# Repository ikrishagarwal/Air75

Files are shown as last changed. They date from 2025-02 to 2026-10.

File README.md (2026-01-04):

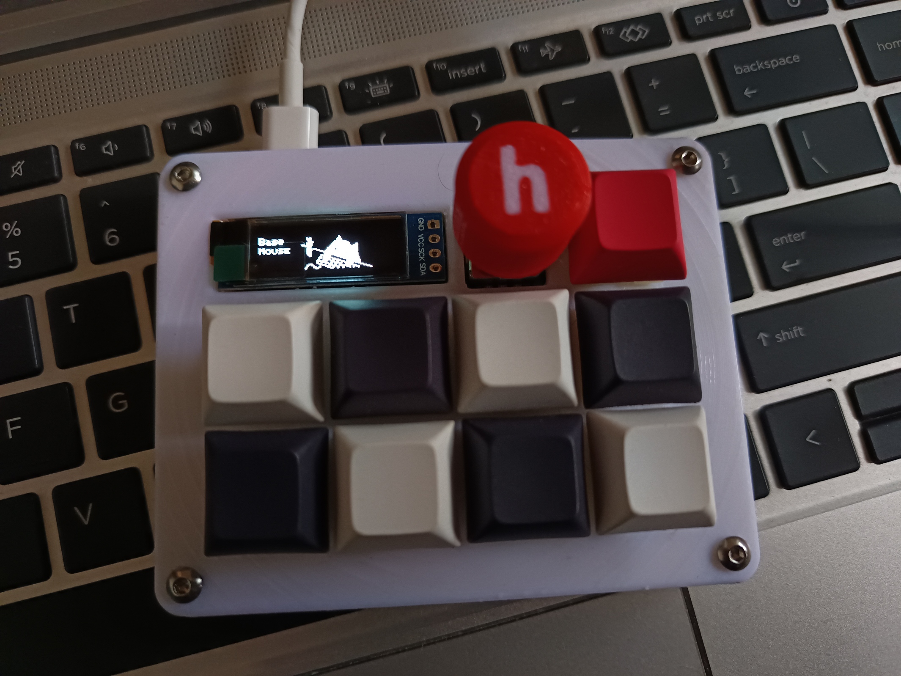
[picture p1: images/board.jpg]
air75


# Air 75

A Macro Pad with rotary encoders and OLED display.

## Specifications

### BOM

- 9x Cherry MX Switches
- 9x Blank DSA Keycaps (1x Red, 4x White, 4x Black)
- 1x Rotary Encoder
- 1x 128x32 OLED Display
- 10x 1N4148 Diodes
- 1x XIAO RP2040
- 4x M3x16 Bolt

# Features

- Rotary Encoder Support
- OLED Display Support
- VIA Support
- Based on QMK

### Other Resources

- [PCB](PCB)
- [Images](images)

| Schematic | PCB | Case |
| :---: | :---: | :---: |
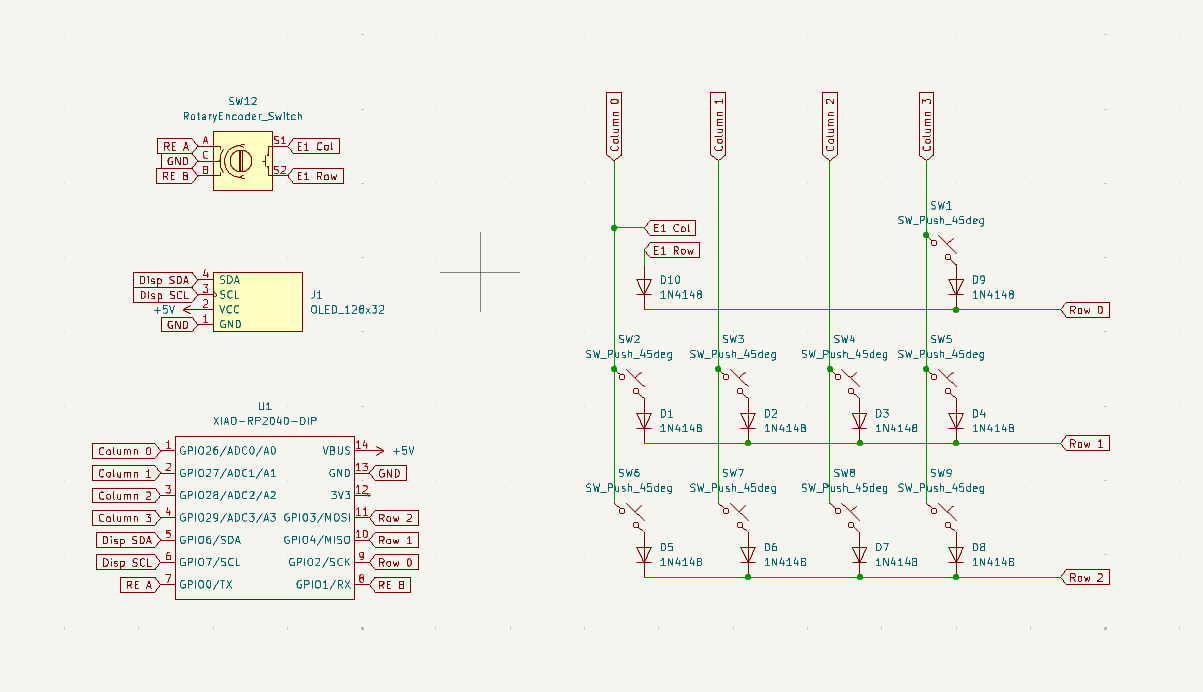
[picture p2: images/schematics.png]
schematic
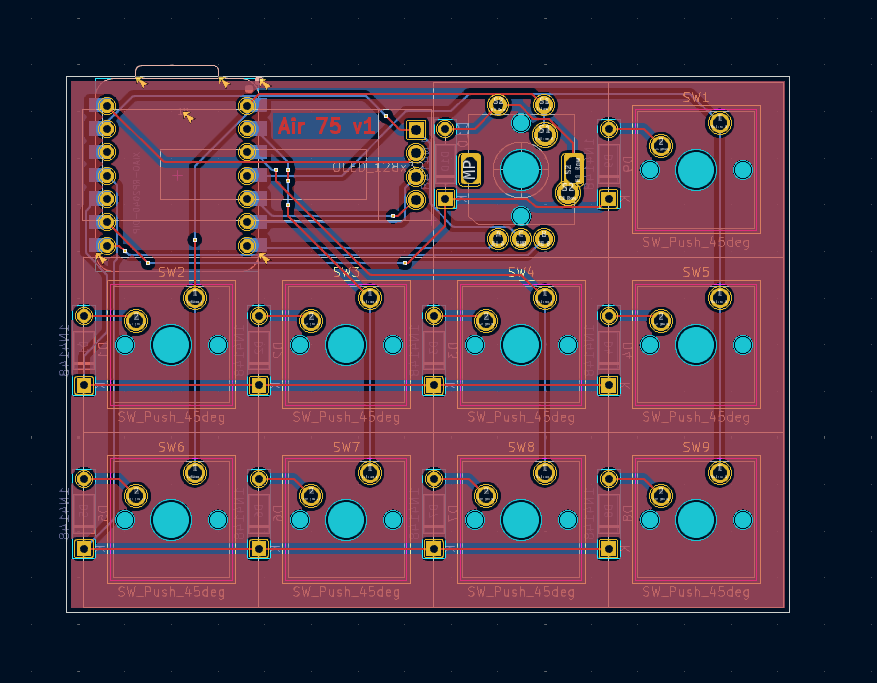
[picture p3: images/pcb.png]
pcb
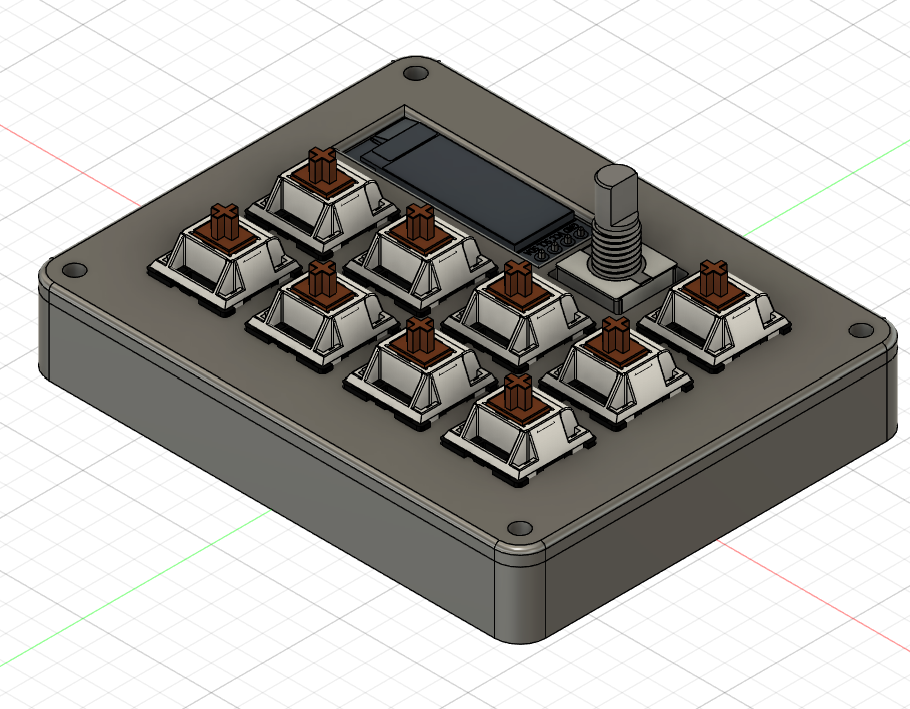
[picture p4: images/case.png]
case
|  |  |  |

## Author

- [Krish](https://github.com/ikrishagarwal)

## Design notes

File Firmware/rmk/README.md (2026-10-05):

# RMK 

RMK is a feature-rich and easy-to-use keyboard firmware.

## Air75 configuration

Edit `keyboard.toml` for the matrix pins and bootmagic key, encoder settings,
keymaps, Vim macro sequences, Vial/storage settings, and OLED hardware and redraw
intervals. RMK generates their setup; `src/main.rs` only invokes the keyboard macro.

The bongo-cat renderer and bitmap artwork remain in `src/bongocat_renderer.rs` and
`src/bongocat_frames.rs`. The build script derives OLED layer names and encoder
labels from the TOML's default keymap, so those labels need no separate Rust edits.
Labels describe the compiled defaults, not encoder mappings changed through Vial.

Use `clear_storage = false` to preserve saved Vial settings. Set it to `true`
only for an intentional reset, then restore `false` before normal use.

## Use the template

1. Install [probe-rs](https://github.com/probe-rs/probe-rs)

   ```shell
   # Linux/macOS
   curl --proto '=https' --tlsv1.2 -LsSf https://github.com/probe-rs/probe-rs/releases/latest/download/probe-rs-tools-installer.sh | sh

   # Windows
   irm https://github.com/probe-rs/probe-rs/releases/latest/download/probe-rs-tools-installer.ps1 | iex
   ```

2. Build the firmware

   ```shell
   cargo build --release
   ```

3. Flash using debug probe

   If you have a debug probe connected to your rp2040 board, flashing is quite simple: run the following command to automatically compile and flash RMK firmware to the board:

   ```shell
   cargo run --release
   ```

4. (Optional) Flash using USB

   If you don't have a debug probe, you can use `elf2uf2-rs` to flash your rp2040 firmware via USB. There are several additional steps you have to do:

   1. Install `elf2uf2-rs`: `cargo install elf2uf2-rs`
   2. Update `.cargo/config.toml`, use `elf2uf2` as the flashing tool
      ```diff
      - runner = "probe-rs run --chip RP2040"
      + runner = "elf2uf2-rs -d"
      ```
   3. Connect your rp2040 board holding the BOOTSEL key, ensure that rp's USB drive appears
   4. Flash
      ```shell
      cargo run --release
      ```
      Then, you will see logs like if everything goes right:
      ```shell
      Finished release [optimized + debuginfo] target(s) in 0.21s
      Running `elf2uf2-rs -d 'target\thumbv6m-none-eabi\release\rmk-rp2040'`
      Found pico uf2 disk G:\
      Transfering program to pico
      173.00 KB / 173.00 KB [=======================] 100.00 % 193.64 KB/s  
      ```

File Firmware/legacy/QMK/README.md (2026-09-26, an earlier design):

# Air75

air75

A Macro Pad designed for productivity and efficiency, featuring a rotary encoder and an OLED display for enhanced functionality.

- Keyboard Maintainer: [Krish](https://github.com/ikrishagarwal)
- Hardware Supported: _Seeed Xiao RP2040_

Make example for this keyboard (after setting up your build environment):

```
make air75:via
```

Flashing example for this keyboard:

```
make air75:via:flash
```

See the [build environment setup](https://docs.qmk.fm/#/getting_started_build_tools) and the [make instructions](https://docs.qmk.fm/#/getting_started_make_guide) for more information. Brand new to QMK? Start with our [Complete Newbs Guide](https://docs.qmk.fm/#/newbs).

## Bootloader

Enter the bootloader in 3 ways:

- **Bootmagic reset**: Hold down the Rotary Encoder and plug in the keyboard
- **Physical reset button**: Hold down the `boot` button on the Xiao and plug in the keyboard
- **Keycode in layout**: Press the key mapped to `QK_BOOT` if it is available

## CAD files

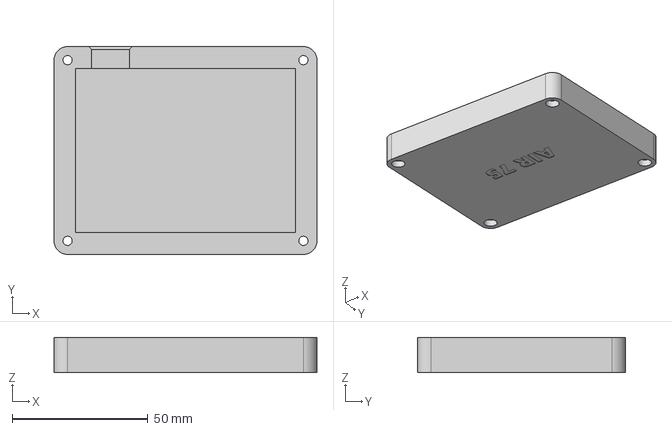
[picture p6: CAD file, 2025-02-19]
CAD/Bottom Case.step
96.7 x 76.5 x 13.0 mm

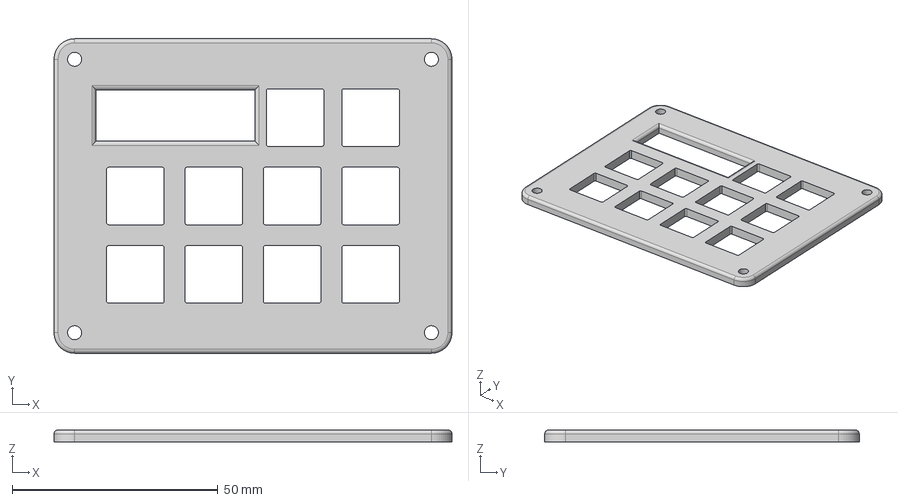
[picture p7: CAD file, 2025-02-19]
Production/Top Case.step
96.7 x 76.5 x 3.00 mm

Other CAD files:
CAD/Air75 v1.f3d

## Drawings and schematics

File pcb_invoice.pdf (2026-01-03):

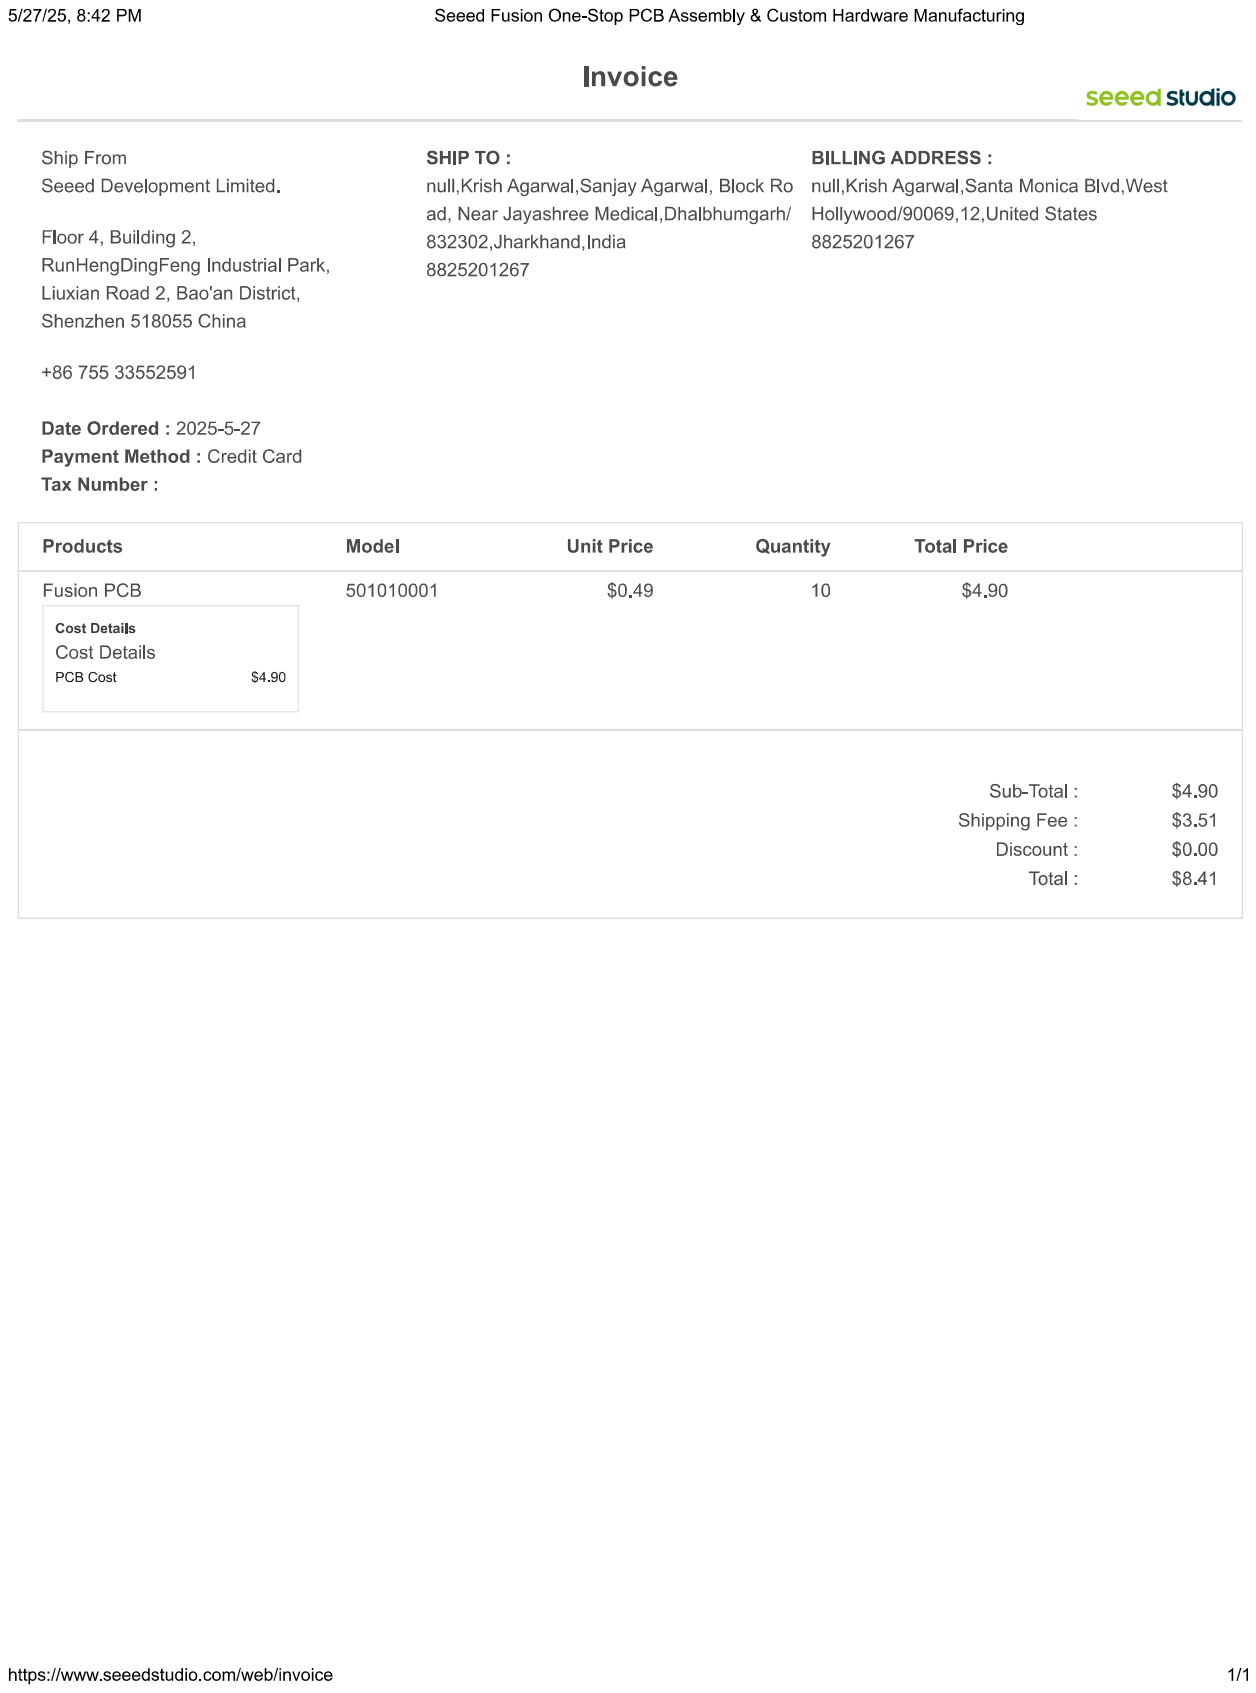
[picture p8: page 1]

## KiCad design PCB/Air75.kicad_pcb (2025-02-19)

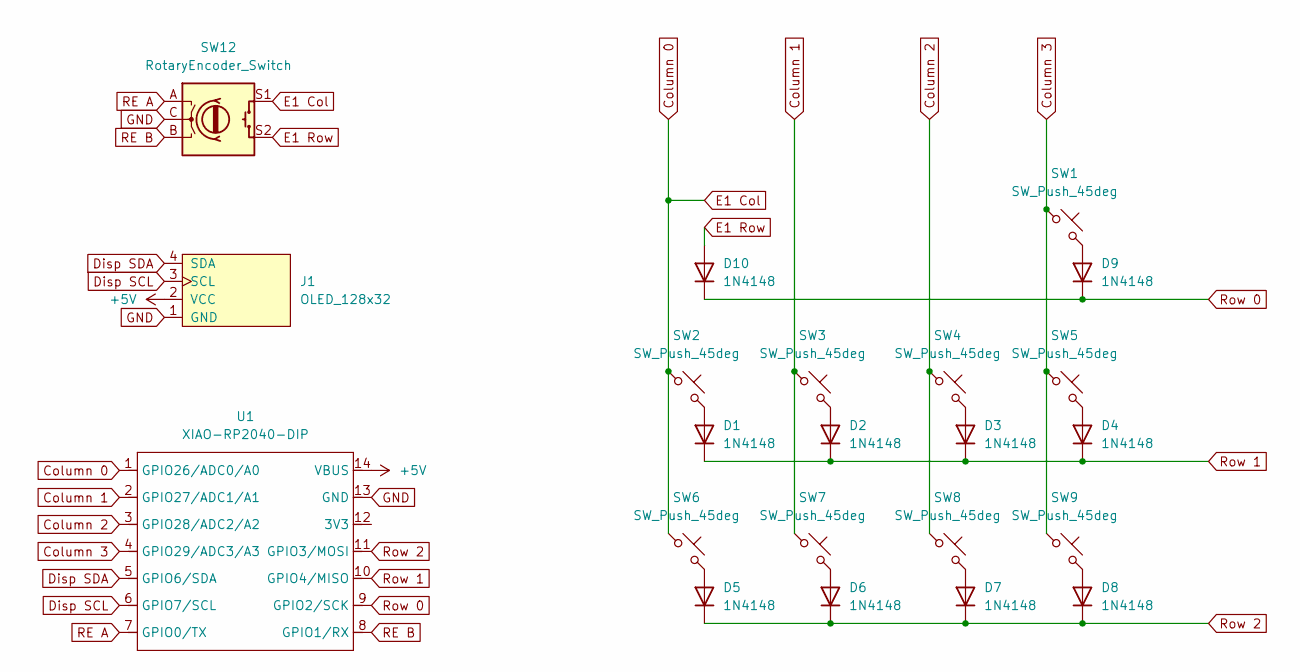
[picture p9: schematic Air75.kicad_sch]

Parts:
D1, D2, D3, D4, D5, D6, D7, D8, D9, D10: 1N4148; D_DO-35_SOD27_P7.62mm_Horizontal
J1: OLED_128x32
SW1, SW2, SW3, SW4, SW5, SW6, SW7, SW8, SW9: SW_Push_45deg; MX_PCB_1.00u
SW12: RotaryEncoder_Switch; Encoder_EC11_MX_Combo
U1: XIAO-RP2040-DIP

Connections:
+5V: J1.2 (VCC), U1.14 (VBUS)
Column 0: SW2.1, SW6.1, SW12.S1, U1.1 (GPIO26/ADC0/A0)
Column 1: SW3.1, SW7.1, U1.2 (GPIO27/ADC1/A1)
Column 2: SW4.1, SW8.1, U1.3 (GPIO28/ADC2/A2)
Column 3: SW1.1, SW5.1, SW9.1, U1.4 (GPIO29/ADC3/A3)
Disp SCL: J1.3 (SCL), U1.6 (GPIO7/SCL)
Disp SDA: J1.4 (SDA), U1.5 (GPIO6/SDA)
E1 Row: D10.2 (A), SW12.S2
GND: J1.1 (GND), SW12.C, U1.13 (GND)
unnamed: D1.2 (A), SW2.2
unnamed: D2.2 (A), SW3.2
unnamed: D3.2 (A), SW4.2
unnamed: D4.2 (A), SW5.2
unnamed: D5.2 (A), SW6.2
unnamed: D6.2 (A), SW7.2
unnamed: D7.2 (A), SW8.2
unnamed: D8.2 (A), SW9.2
unnamed: D9.2 (A), SW1.2
RE A: SW12.A, U1.7 (GPIO0/TX)
RE B: SW12.B, U1.8 (GPIO1/RX)
Row 0: D9.1 (K), D10.1 (K), U1.9 (GPIO2/SCK)
Row 1: D1.1 (K), D2.1 (K), D3.1 (K), D4.1 (K), U1.10 (GPIO4/MISO)
Row 2: D5.1 (K), D6.1 (K), D7.1 (K), D8.1 (K), U1.11 (GPIO3/MOSI)

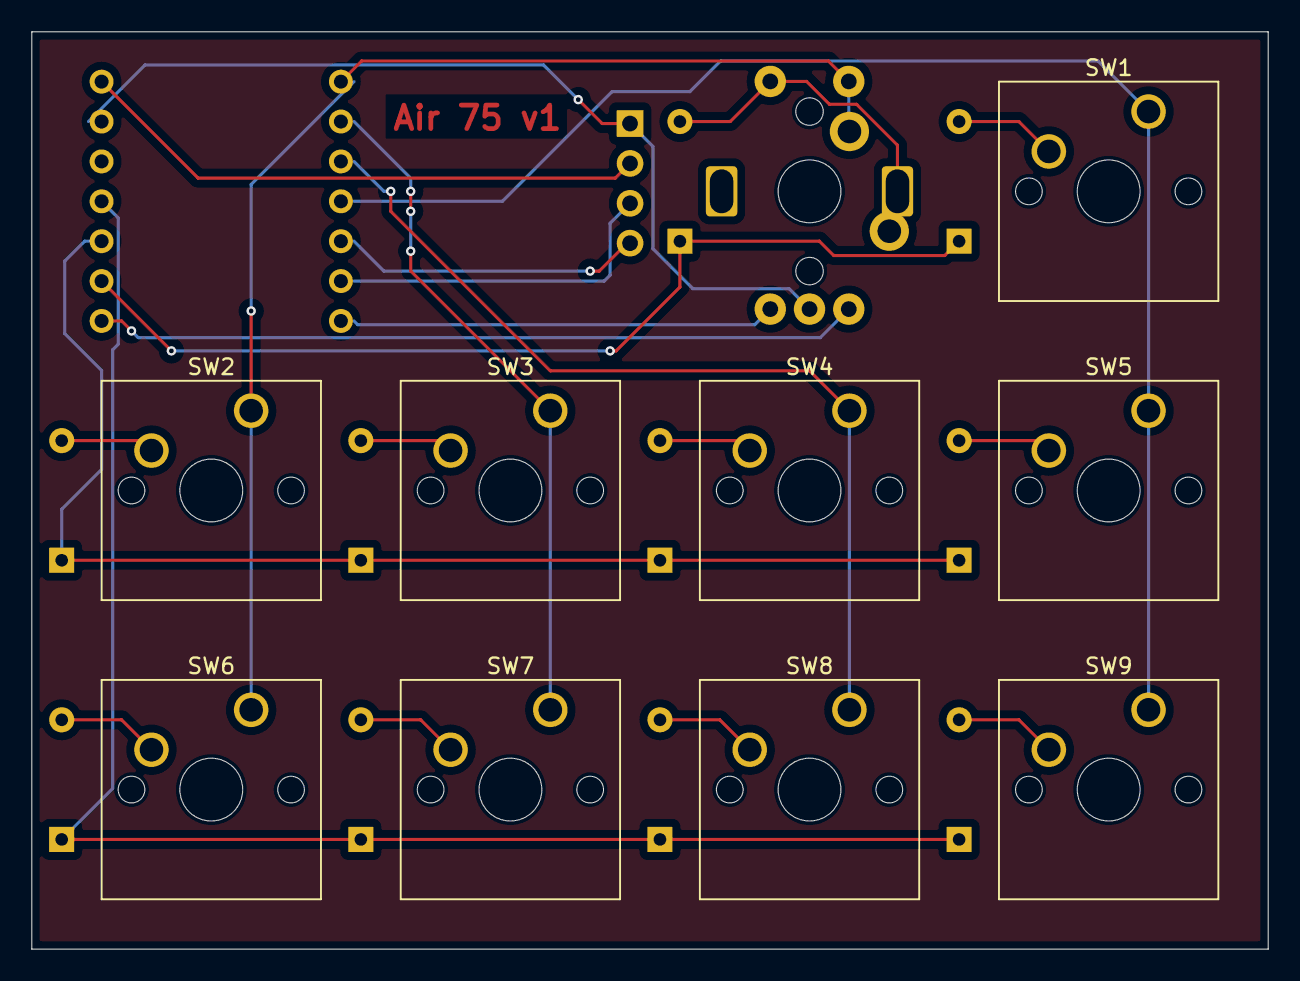
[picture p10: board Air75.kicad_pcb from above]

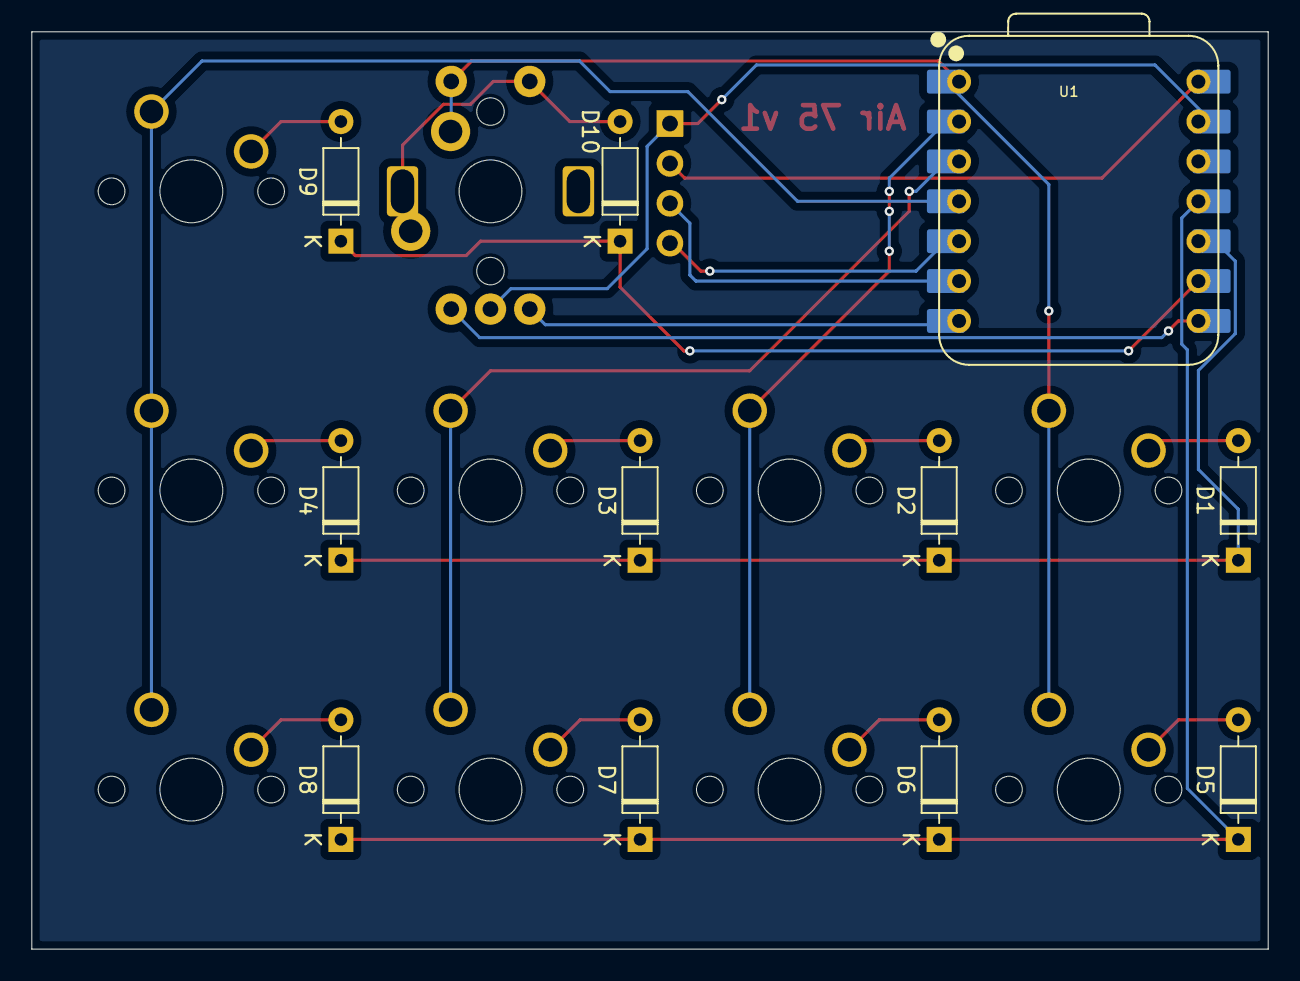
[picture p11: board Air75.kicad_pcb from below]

Board: 2 copper layers, 78.7 x 58.4 mm, 22 parts (11 on the bottom side), 23 nets.

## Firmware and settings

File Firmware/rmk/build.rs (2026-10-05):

//! This build script copies the `memory.x` file from the crate root into
//! a directory where the linker can always find it at build time.
//! For many projects this is optional, as the linker always searches the
//! project root directory -- wherever `Cargo.toml` is. However, if you
//! are using a workspace or have a more complicated build setup, this
//! build script becomes required. Additionally, by requesting that
//! Cargo re-run the build script whenever `memory.x` is changed,
//! updating `memory.x` ensures a rebuild of the application with the
//! new memory settings.
//!
//! The build script also sets the linker flags to tell it which link script to use.

use const_gen::*;
use std::fs::File;
use std::io::{Read, Write};
use std::path::{Path, PathBuf};
use std::{env, fs};
use xz2::read::XzEncoder;

fn main() {
    // Generate vial config at the root of project
    println!("cargo:rerun-if-changed=vial.json");
    println!("cargo:rerun-if-changed=keyboard.toml");

    generate_vial_config();
    generate_display_config();

    // Put `memory.x` in our output directory and ensure it's
    // on the linker search path.
    let out = &PathBuf::from(env::var_os("OUT_DIR").unwrap());
    File::create(out.join("memory.x"))
        .unwrap()
        .write_all(include_bytes!("memory.x"))
        .unwrap();
    println!("cargo:rustc-link-search={}", out.display());

    // By default, Cargo will re-run a build script whenever
    // any file in the project changes. By specifying `memory.x`
    // here, we ensure the build script is only re-run when
    // `memory.x` is changed.
    println!("cargo:rerun-if-changed=memory.x");

    // Specify linker arguments.

    // `--nmagic` is required if memory section addresses are not aligned to 0x10000,
    // for example the FLASH and RAM sections in your `memory.x`.
    // See https://github.com/rust-embedded/cortex-m-quickstart/pull/95
    println!("cargo:rustc-link-arg=--nmagic");

    // Set the linker script to the one provided by cortex-m-rt.
    println!("cargo:rustc-link-arg=-Tlink.x");

    // Set the linker script of the defmt
    println!("cargo:rustc-link-arg=-Tdefmt.x");

    println!("cargo:rustc-linker=flip-link");
}

fn generate_display_config() {
    let content = fs::read_to_string("keyboard.toml").expect("Cannot read keyboard.toml");
    let declarations = display_config_declarations(&content)
        .unwrap_or_else(|error| panic!("Invalid display metadata in keyboard.toml: {error}"));
    let out_file = Path::new(&env::var_os("OUT_DIR").unwrap()).join("display_config_generated.rs");
    fs::write(out_file, declarations).expect("Cannot write display_config_generated.rs");
}

fn display_config_declarations(content: &str) -> Result<String, String> {
    let config: toml::Value =
        toml::from_str(content).map_err(|error| format!("Cannot parse TOML: {error}"))?;
    let layers = config
        .get("keymap")
        .and_then(|keymap| keymap.get("layer"))
        .and_then(toml::Value::as_array)
        .ok_or("Expected [[keymap.layer]] entries")?;
    let size = config
        .get("display")
        .and_then(|display| display.get("size"))
        .and_then(toml::Value::as_str)
        .ok_or("Expected [display].size as a WIDTHxHEIGHT string")?;
    let (width, height) = display_dimensions(size)?;

    let mut names = Vec::with_capacity(layers.len());
    let mut purposes = Vec::with_capacity(layers.len());
    for (index, layer) in layers.iter().enumerate() {
        let layer = layer
            .as_table()
            .ok_or_else(|| format!("keymap.layer[{index}] must be a table"))?;
        let name = match layer.get("name") {
            Some(name) => name
                .as_str()
                .ok_or_else(|| format!("keymap.layer[{index}].name must be a string"))?,
            None => "",
        };
        // Debug formatting produces a properly escaped Rust string literal,
        // including quotes, backslashes, newlines, and control characters.
        names.push(format!("{name:?}"));
        purposes.push(format!("{:?}", encoder_purpose(layer.get("encoders"))));
    }

    Ok(format!(
        "// Generated from keyboard.toml; do not edit.\n\
         pub const LAYER_NAMES: [&str; {count}] = [{names}];\n\
         pub const ENCODER_PURPOSES: [&str; {count}] = [{purposes}];\n\
         pub const DISPLAY_WIDTH: u32 = {width};\n\
         pub const DISPLAY_HEIGHT: u32 = {height};\n",
        count = layers.len(),
        names = names.join(", "),
        purposes = purposes.join(", "),
    ))
}

fn display_dimensions(size: &str) -> Result<(u32, u32), String> {
    let invalid = || {
        format!(
            "Invalid display size {size:?}; expected positive WIDTHxHEIGHT dimensions fitting i32"
        )
    };
    let (width, height) = size.split_once('x').ok_or_else(invalid)?;
    let parse = |dimension: &str| {
        if dimension.is_empty() || !dimension.bytes().all(|byte| byte.is_ascii_digit()) {
            return Err(invalid());
        }
        dimension
            .parse::<u32>()
            // Drawing coordinates are signed, while embedded-graphics sizes are u32.
            .ok()
            .filter(|&value| value > 0 && value <= i32::MAX as u32)
            .ok_or_else(invalid)
    };
    Ok((parse(width)?, parse(height)?))
}

fn encoder_purpose(encoders: Option<&toml::Value>) -> &'static str {
    let Some(pair) = encoders
        .and_then(toml::Value::as_array)
        .and_then(|encoders| encoders.first())
        .and_then(toml::Value::as_array)
    else {
        return "";
    };
    if pair.len() != 2 {
        return "";
    }
    match (pair[0].as_str(), pair[1].as_str()) {
        (Some("MouseWheelDown"), Some("MouseWheelUp"))
        | (Some("MouseWheelUp"), Some("MouseWheelDown")) => "MOUSE",
        (Some("AudioVolDown"), Some("AudioVolUp")) | (Some("AudioVolUp"), Some("AudioVolDown")) => {
            "VOLUME"
        }
        _ => "",
    }
}

fn generate_vial_config() {
    // Generated vial config file
    let out_file = Path::new(&env::var_os("OUT_DIR").unwrap()).join("config_generated.rs");

    let p = Path::new("vial.json");
    let mut content = String::new();
    match File::open(p) {
        Ok(mut file) => {
            file.read_to_string(&mut content)
                .expect("Cannot read vial.json");
        }
        Err(e) => println!("Cannot find vial.json {:?}: {}", p, e),
    };

    let vial_cfg = json::stringify(json::parse(&content).unwrap());
    let mut keyboard_def_compressed: Vec<u8> = Vec::new();
    XzEncoder::new(vial_cfg.as_bytes(), 6)
        .read_to_end(&mut keyboard_def_compressed)
        .unwrap();

    let keyboard_id: Vec<u8> = vec![0xB9, 0xBC, 0x09, 0xB2, 0x9D, 0x37, 0x4C, 0xEA];
    let const_declarations = [
        const_declaration!(pub VIAL_KEYBOARD_DEF = keyboard_def_compressed),
        const_declaration!(pub VIAL_KEYBOARD_ID = keyboard_id),
    ]
    .join("\n");
    fs::write(out_file, const_declarations).unwrap();
}

#[cfg(test)]
mod tests {
    use super::*;

    fn declarations(layers: &str) -> String {
        display_config_declarations(&format!("[display]\nsize = \"128x32\"\n{layers}"))
            .expect("valid metadata")
    }

    #[test]
    fn metadata_follows_actual_layers_and_defaults_missing_names() {
        let generated = declarations(
            r#"
[keymap]
layers = 99
[[keymap.layer]]
name = "General"
encoders = [["MouseWheelDown", "MouseWheelUp"]]
[[keymap.layer]]
encoders = [["AudioVolUp", "AudioVolDown"]]
[[keymap.layer]]
name = "Other"
"#,
        );
        assert!(generated
            .contains("pub const LAYER_NAMES: [&str; 3] = [\"General\", \"\", \"Other\"];"));
        assert!(generated
            .contains("pub const ENCODER_PURPOSES: [&str; 3] = [\"MOUSE\", \"VOLUME\", \"\"];"));
        assert!(generated.contains("pub const DISPLAY_WIDTH: u32 = 128;"));
        assert!(generated.contains("pub const DISPLAY_HEIGHT: u32 = 32;"));
    }

    #[test]
    fn names_are_escaped_as_rust_string_literals() {
        let generated = declarations(
            r#"
[[keymap.layer]]
name = "\"\\\n\t\r\u0000\u001B猫"
"#,
        );
        assert!(
            generated.contains(r#"pub const LAYER_NAMES: [&str; 1] = ["\"\\\n\t\r\0\u{1b}猫"];"#)
        );
    }

    #[test]
    fn exact_encoder_pairs_are_classified_in_either_order() {
        for (pair, expected) in [
            (r#"["MouseWheelDown", "MouseWheelUp"]"#, "MOUSE"),
            (r#"["MouseWheelUp", "MouseWheelDown"]"#, "MOUSE"),
            (r#"["AudioVolDown", "AudioVolUp"]"#, "VOLUME"),
            (r#"["AudioVolUp", "AudioVolDown"]"#, "VOLUME"),
        ] {
            let config: toml::Value = toml::from_str(&format!("encoders = [{pair}]")).unwrap();
            assert_eq!(encoder_purpose(config.get("encoders")), expected);
        }
    }

    #[test]
    fn other_or_missing_mappings_have_no_label_and_only_first_encoder_is_used() {
        assert_eq!(encoder_purpose(None), "");
        for encoders in [
            "[]",
            "[[]]",
            r#"[["MouseWheelDown"]]"#,
            r#"[["MouseWheelDown", "MouseWheelUp", "No"]]"#,
            r#"[["MouseWheelDown", "MouseWheelDown"]]"#,
            r#"[["MouseWheelDown", "AudioVolUp"]]"#,
            r#"[["WM(MouseWheelDown, LCtrl)", "MouseWheelUp"]]"#,
            r#"[["No", "No"], ["MouseWheelDown", "MouseWheelUp"]]"#,
            r#"["MouseWheelDown", "MouseWheelUp"]"#,
            "[[1, 2]]",
            "false",
        ] {
            let config: toml::Value = toml::from_str(&format!("encoders = {encoders}")).unwrap();
            assert_eq!(encoder_purpose(config.get("encoders")), "", "{encoders}");
        }
        let config: toml::Value = toml::from_str(
            "encoders = [[\"MouseWheelUp\", \"MouseWheelDown\"], [\"AudioVolUp\", \"AudioVolDown\"]]",
        )
        .unwrap();
        assert_eq!(encoder_purpose(config.get("encoders")), "MOUSE");
    }

    #[test]
    fn dimensions_are_positive_and_safe_for_drawing_coordinates() {
        assert_eq!(display_dimensions("128x32"), Ok((128, 32)));
        assert_eq!(display_dimensions("1x1"), Ok((1, 1)));
        assert_eq!(display_dimensions("2147483647x1"), Ok((i32::MAX as u32, 1)));
        for size in [
            "",
            "128",
            "128X32",
            "128x32x1",
            "0x32",
            "128x0",
            "-1x32",
            "128x-1",
            "1.5x32",
            "x32",
            "128x",
            "+1x32",
            " 128x32",
            "128x32 ",
            "2147483648x1",
            "1x2147483648",
            "4294967296x32",
        ] {
            assert!(display_dimensions(size).is_err(), "accepted {size:?}");
        }
    }

    #[test]
    fn invalid_toml_or_missing_required_metadata_is_rejected() {
        for config in [
            "[broken",
            "[[keymap.layer]]\nname = \"No display\"",
            "[display]\nsize = \"128x32\"",
            "[display]\nsize = 128\n[[keymap.layer]]",
            "[display]\nsize = \"0x32\"\n[[keymap.layer]]",
            "[display]\nsize = \"128x32\"\n[[keymap.layer]]\nname = 1",
            "[display]\nsize = \"128x32\"\n[keymap]\nlayer = [1]",
        ] {
            assert!(
                display_config_declarations(config).is_err(),
                "accepted {config:?}"
            );
        }
    }
}

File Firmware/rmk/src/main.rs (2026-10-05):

#![no_main]
#![no_std]

mod bongocat_frames;
mod bongocat_renderer;

// RMK generates hardware setup, storage, macros, and the display task from TOML.
#[rmk::macros::rmk_keyboard]
mod keyboard {
    // RMK's USB transport reports laptop suspend/resume through the connection
    // status event. Bridge that state to the sleep event consumed by the
    // display processor so the OLED follows the host's lid state.
    #[register_processor(event)]
    fn usb_sleep_bridge() {
        #[rmk::macros::processor(subscribe = [::rmk::event::ConnectionStatusChangeEvent])]
        struct UsbSleepBridge;

        impl UsbSleepBridge {
            async fn on_connection_status_change_event(
                &mut self,
                event: ::rmk::event::ConnectionStatusChangeEvent,
            ) {
                let sleeping = event.0.usb == ::rmk::types::connection::UsbState::Suspended;
                ::rmk::event::publish_event(::rmk::event::SleepStateEvent::new(sleeping));
            }
        }

        UsbSleepBridge
    }
}

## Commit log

2025-02-17 made the pcb
    [Air75.kicad_pcb, Air75.kicad_sch]
2025-02-18 fix: remove right angles from pcb
    [Air75.kicad_pcb, Air75.kicad_sch]
2025-02-18 fix: fix pcb
    [Air75.kicad_pcb]
2025-02-19 added everything
    [Air75 v1.f3d, Air75.kicad_pcb, Bottom Case.step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]
2026-01-03 feat: switch to qmk
2026-10-05 fix: RE jitter
